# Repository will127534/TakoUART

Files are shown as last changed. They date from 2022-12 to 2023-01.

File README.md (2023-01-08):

# TakoUART - 8ch USB to UART board



This 5cm x 5cm 4-layer board is based on [CH348Q](http://www.wch-ic.com/products/CH348.html?) USB to 8 UART IC, I've also added level shifter (NTS0302JKZ) along with a overcurrent protector(NCP380) for user selectable 3.3V output on each UART port.

The board is designed with Kicad 6.0:



#inaART

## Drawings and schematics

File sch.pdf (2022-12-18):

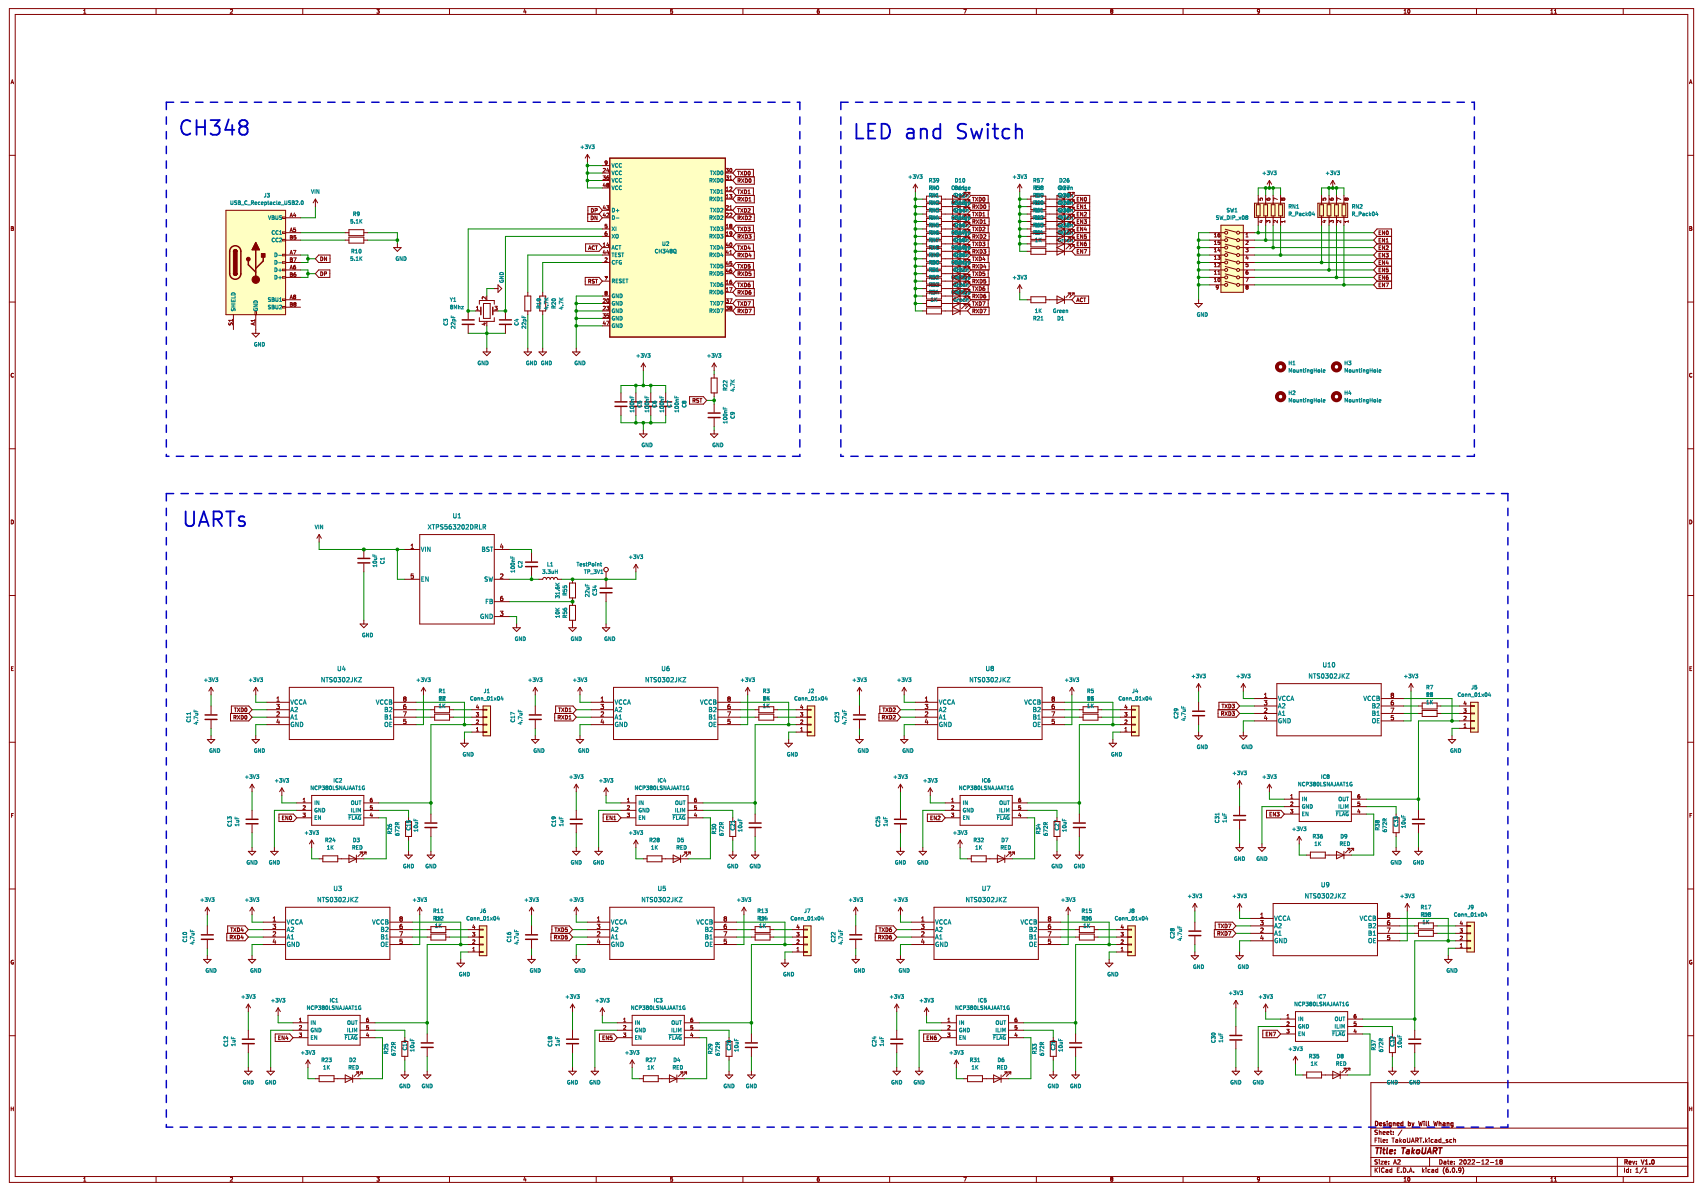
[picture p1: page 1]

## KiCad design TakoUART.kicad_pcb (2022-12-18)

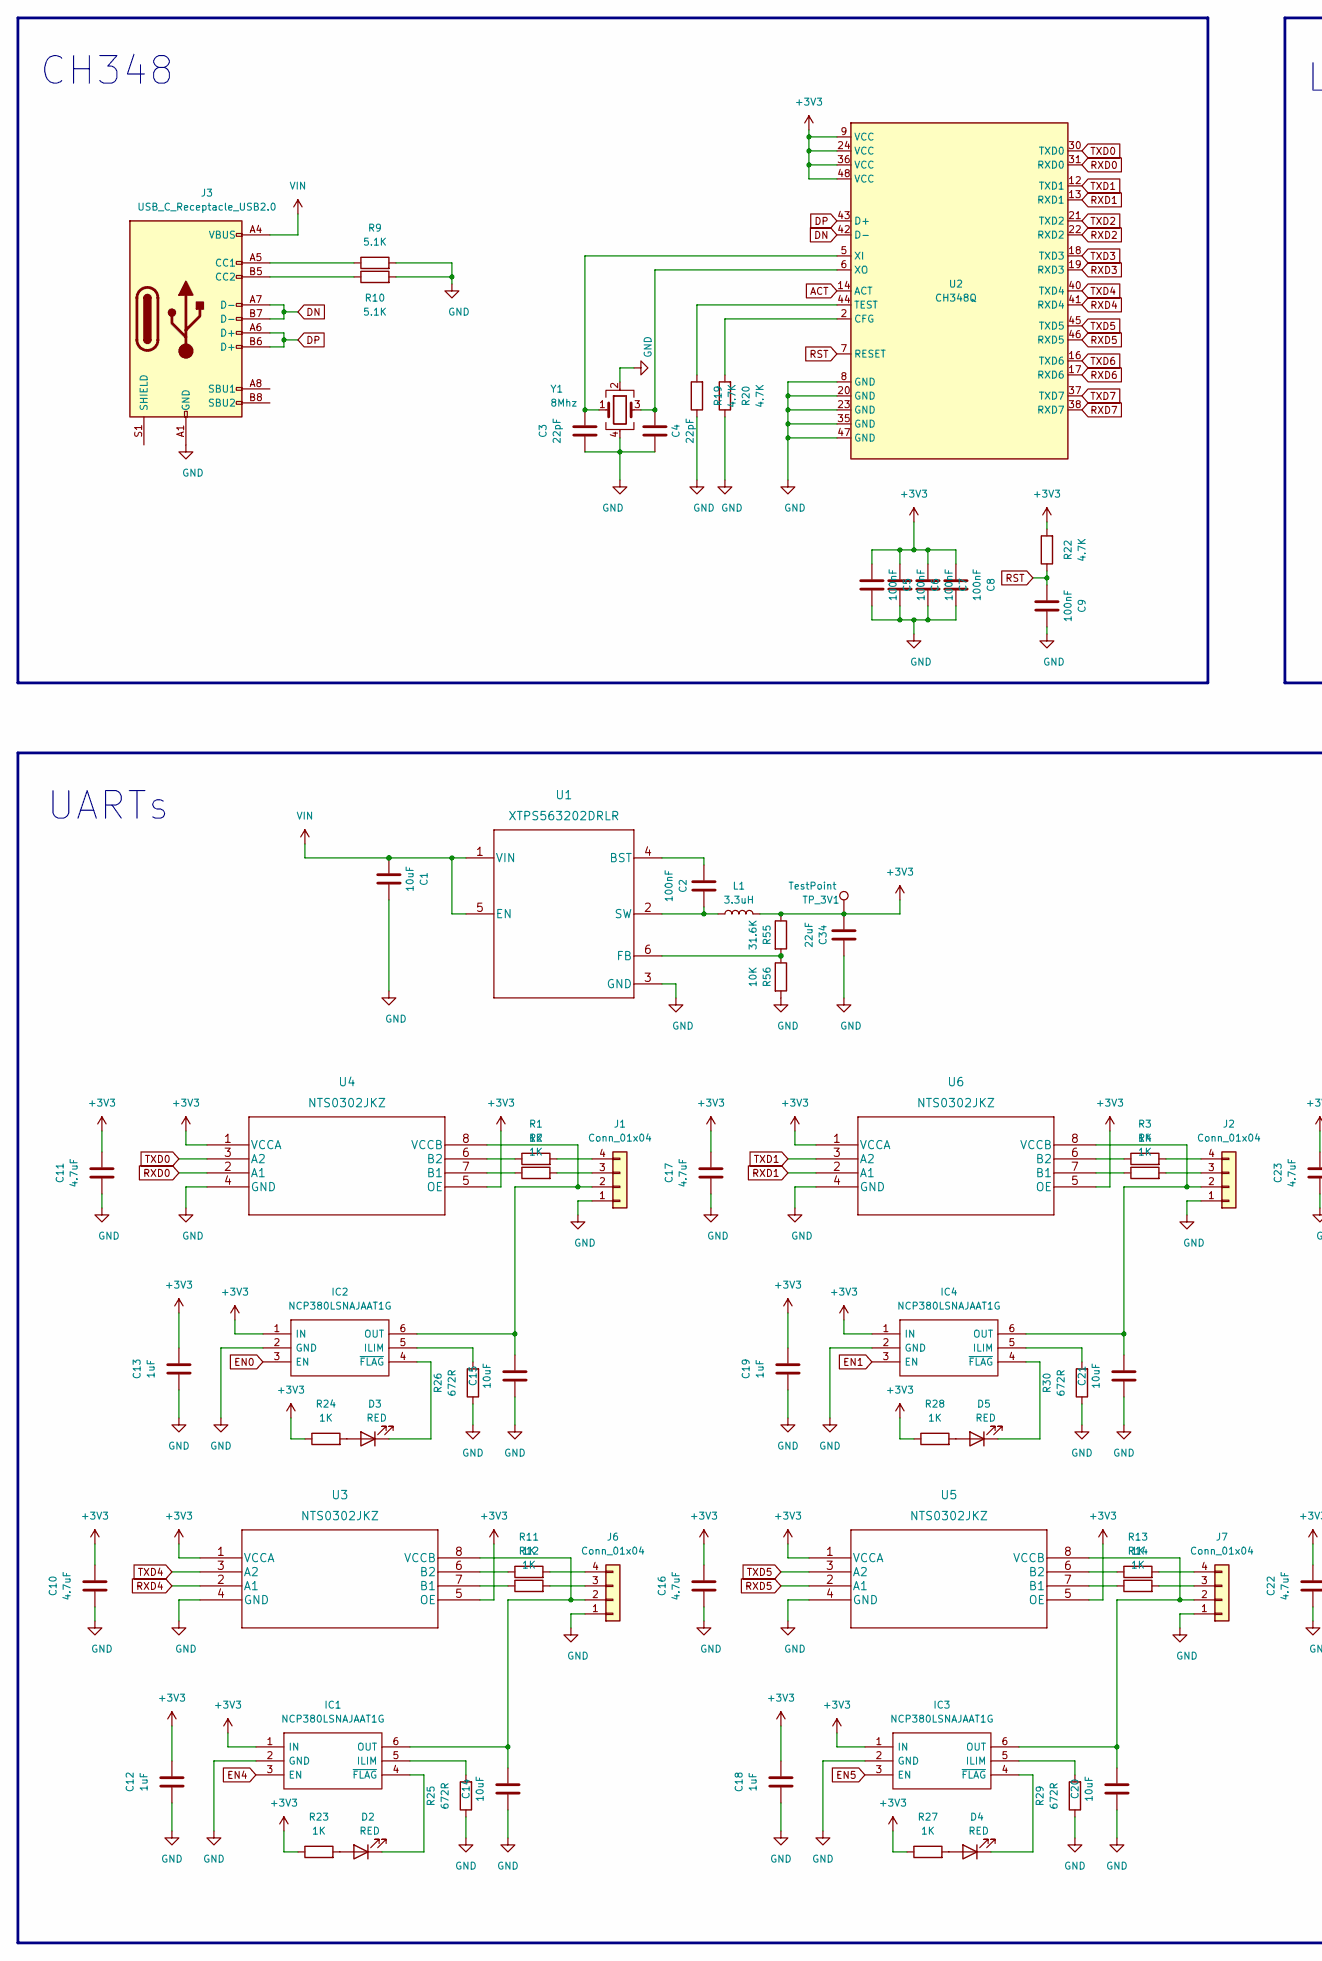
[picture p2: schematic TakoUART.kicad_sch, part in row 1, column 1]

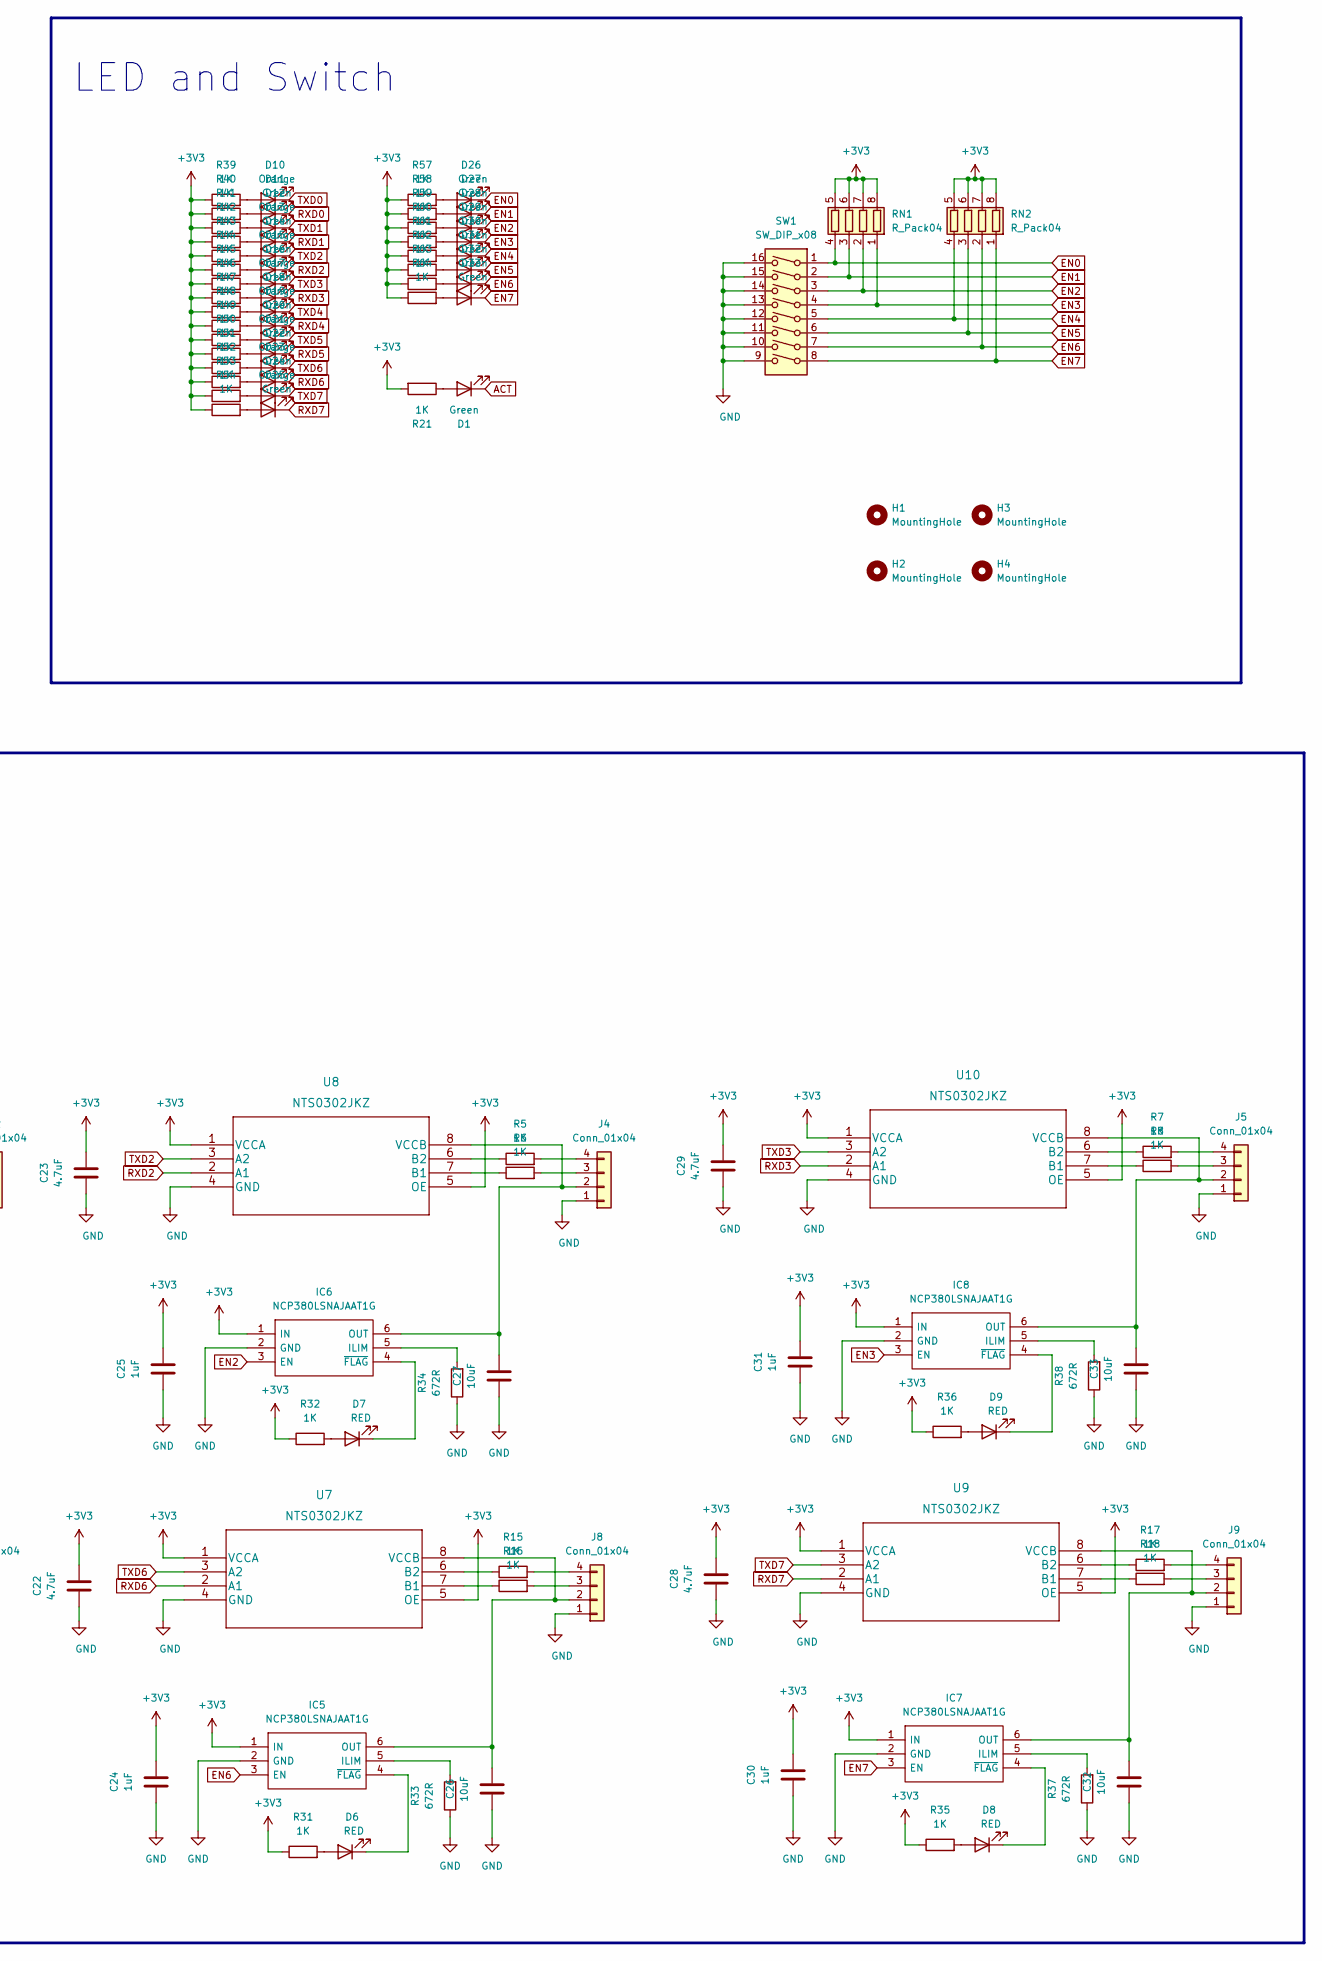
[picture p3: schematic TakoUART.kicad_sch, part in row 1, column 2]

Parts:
C1: 10uF; C_0805_2012Metric
C2, C5, C6, C7, C8, C9: 100nF; C_0402_1005Metric
C3, C4: 22pF; C_0402_1005Metric
C10, C11, C16, C17, C22, C23, C28, C29: 4.7uF; C_0402_1005Metric
C12, C13, C18, C19, C24, C25, C30, C31: 1uF; C_0402_1005Metric
C14, C15, C20, C21, C26, C27, C32, C33: 10uF; C_0402_1005Metric
C34: 22uF; C_0805_2012Metric
D1, D11, D13, D15, D17, D19, D21, D23, D25, D26, D27, D28, D29, D30, D31, D32, D33: Green; LED_0402_1005Metric
D2, D3, D4, D5, D6, D7, D8, D9: RED; LED_0402_1005Metric
D10, D12, D14, D16, D18, D20, D22, D24: Orange; LED_0402_1005Metric
H1, H2, H3, H4: MountingHole; MountingHole_3.2mm_M3
IC1, IC2, IC3, IC4, IC5, IC6, IC7, IC8: NCP380LSNAJAAT1G; SOT95P275X110-6N; Mouser Part Number 863-NCP380LSNAJAAT1G
J1, J2, J4, J5, J6, J7, J8, J9: Conn_01x04; JST_SH_BM04B-SRSS-TB_1x04-1MP_P1.00mm_Vertical
J3: USB_C_Receptacle_USB2.0; USB_C_Receptacle_XKB_U262-16XN-4BVC11
L1: 3.3uH; L_Vishay_IHLP-1212
R1, R2, R3, R4, R5, R6, R7, R8, R11, R12, R13, R14, R15, R16, R17, R18, R21, R23, R24, R27, R28, R31, R32, R35, R36, R39, R40, R41, R42, R43, R44, R45, R46, R47, R48, R49, R50, R51, R52, R53, R54, R57, R58, R59, R60, R61, R62, R63, R64: 1K; R_0402_1005Metric
R9, R10: 5.1K; R_0402_1005Metric
R19, R20, R22: 4.7K; R_0402_1005Metric
R25, R26, R29, R30, R33, R34, R37, R38: 672R; R_0402_1005Metric
R55: 31.6K; R_0402_1005Metric
R56: 10K; R_0402_1005Metric
RN1, RN2: R_Pack04; R_Array_Concave_4x0603
SW1: SW_DIP_x08; SW_DIP_SPSTx08_Slide_6.7x21.88mm_W8.61mm_P2.54mm_LowProfile
TP_3V1: TestPoint; TestPoint_Pad_D1.0mm
U1: XTPS563202DRLR
U2: CH348Q; LQFP-48_7x7mm_P0.5mm
U3, U4, U5, U6, U7, U8, U9, U10: NTS0302JKZ
Y1: 8Mhz; Crystal_SMD_3225-4Pin_3.2x2.5mm

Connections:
+3V3: C5.1, C6.1, C7.1, C8.1, C10.2, C11.2, C12.2, C13.2, C16.2, C17.2, C18.2, C19.2, C22.2, C23.2, C24.2, C25.2, C28.2, C29.2, C30.2, C31.2, C34.1, IC1.1 (IN), IC2.1 (IN), IC3.1 (IN), IC4.1 (IN), IC5.1 (IN), IC6.1 (IN), IC7.1 (IN), IC8.1 (IN), L1.2, R21.2, R22.2, R23.1, R24.1, R27.1, R28.1, R31.1, R32.1, R35.1, R36.1, R39.1, R40.1, R41.1, R42.1, R43.1, R44.1, R45.1, R46.1, R47.1, R48.1, R49.1, R50.1, R51.1, R52.1, R53.1, R54.1, R55.1, R57.1, R58.1, R59.1, R60.1, R61.1, R62.1, R63.1, R64.1, RN1.5 (R4.2), RN1.6 (R3.2), RN1.7 (R2.2), RN1.8 (R1.2), RN2.5 (R4.2), RN2.6 (R3.2), RN2.7 (R2.2), RN2.8 (R1.2), TP_3V1.1, U2.9 (VCC), U2.24 (VCC), U2.36 (VCC), U2.48 (VCC), U3.1 (VCCA), U3.5 (OE), U4.1 (VCCA), U4.5 (OE), U5.1 (VCCA), U5.5 (OE), U6.1 (VCCA), U6.5 (OE), U7.1 (VCCA), U7.5 (OE), U8.1 (VCCA), U8.5 (OE), U9.1 (VCCA), U9.5 (OE), U10.1 (VCCA), U10.5 (OE)
ACT: D1.1 (K), U2.14 (ACT)
DN: J3.A7 (D-), J3.B7 (D-), U2.42 (D-)
DP: J3.A6 (D+), J3.B6 (D+), U2.43 (D+)
EN0: D26.1 (K), IC2.3 (EN), RN1.4 (R4.1), SW1.1
EN1: D27.1 (K), IC4.3 (EN), RN1.3 (R3.1), SW1.2
EN2: D28.1 (K), IC6.3 (EN), RN1.2 (R2.1), SW1.3
EN3: D29.1 (K), IC8.3 (EN), RN1.1 (R1.1), SW1.4
EN4: D30.1 (K), IC1.3 (EN), RN2.4 (R4.1), SW1.5
EN5: D31.1 (K), IC3.3 (EN), RN2.3 (R3.1), SW1.6
EN6: D32.1 (K), IC5.3 (EN), RN2.2 (R2.1), SW1.7
EN7: D33.1 (K), IC7.3 (EN), RN2.1 (R1.1), SW1.8
GND: C1.2, C3.1, C4.1, C5.2, C6.2, C7.2, C8.2, C9.2, C10.1, C11.1, C12.1, C13.1, C14.1, C15.1, C16.1, C17.1, C18.1, C19.1, C20.1, C21.1, C22.1, C23.1, C24.1, C25.1, C26.1, C27.1, C28.1, C29.1, C30.1, C31.1, C32.1, C33.1, C34.2, IC1.2 (GND), IC2.2 (GND), IC3.2 (GND), IC4.2 (GND), IC5.2 (GND), IC6.2 (GND), IC7.2 (GND), IC8.2 (GND), J1.1, J2.1, J3.A1 (GND), J3.A12 (GND), J3.B1 (GND), J3.B12 (GND), J4.1, J5.1, J6.1, J7.1, J8.1, J9.1, R9.2, R10.2, R19.1, R20.1, R25.1, R26.1, R29.1, R30.1, R33.1, R34.1, R37.1, R38.1, R56.2, SW1.9, SW1.10, SW1.11, SW1.12, SW1.13, SW1.14, SW1.15, SW1.16, U1.3 (GND), U2.8 (GND), U2.20 (GND), U2.23 (GND), U2.35 (GND), U2.47 (GND), U3.4 (GND), U4.4 (GND), U5.4 (GND), U6.4 (GND), U7.4 (GND), U8.4 (GND), U9.4 (GND), U10.4 (GND), Y1.2, Y1.4
unnamed: C2.1, U1.4 (BST)
unnamed: C2.2, L1.1, U1.2 (SW)
unnamed: C3.2, U2.5 (XI), Y1.1
unnamed: C4.2, U2.6 (XO), Y1.3
unnamed: C14.2, IC1.6 (OUT), J6.2, U3.8 (VCCB)
unnamed: C15.2, IC2.6 (OUT), J1.2, U4.8 (VCCB)
unnamed: C20.2, IC3.6 (OUT), J7.2, U5.8 (VCCB)
unnamed: C21.2, IC4.6 (OUT), J2.2, U6.8 (VCCB)
unnamed: C26.2, IC5.6 (OUT), J8.2, U7.8 (VCCB)
unnamed: C27.2, IC6.6 (OUT), J4.2, U8.8 (VCCB)
unnamed: C32.2, IC7.6 (OUT), J9.2, U9.8 (VCCB)
unnamed: C33.2, IC8.6 (OUT), J5.2, U10.8 (VCCB)
unnamed: D1.2 (A), R21.1
unnamed: D2.1 (K), IC1.4 (~FLAG)
unnamed: D2.2 (A), R23.2
unnamed: D3.1 (K), IC2.4 (~FLAG)
unnamed: D3.2 (A), R24.2
unnamed: D4.1 (K), IC3.4 (~FLAG)
unnamed: D4.2 (A), R27.2
unnamed: D5.1 (K), IC4.4 (~FLAG)
unnamed: D5.2 (A), R28.2
unnamed: D6.1 (K), IC5.4 (~FLAG)
unnamed: D6.2 (A), R31.2
unnamed: D7.1 (K), IC6.4 (~FLAG)
unnamed: D7.2 (A), R32.2
unnamed: D8.1 (K), IC7.4 (~FLAG)
unnamed: D8.2 (A), R35.2
unnamed: D9.1 (K), IC8.4 (~FLAG)
unnamed: D9.2 (A), R36.2
unnamed: D10.2 (A), R39.2
unnamed: D11.2 (A), R40.2
unnamed: D12.2 (A), R41.2
unnamed: D13.2 (A), R42.2
unnamed: D14.2 (A), R43.2
unnamed: D15.2 (A), R44.2
unnamed: D16.2 (A), R45.2
unnamed: D17.2 (A), R46.2
unnamed: D18.2 (A), R47.2
unnamed: D19.2 (A), R48.2
unnamed: D20.2 (A), R49.2
unnamed: D21.2 (A), R50.2
unnamed: D22.2 (A), R51.2
unnamed: D23.2 (A), R52.2
unnamed: D24.2 (A), R53.2
unnamed: D25.2 (A), R54.2
unnamed: D26.2 (A), R57.2
unnamed: D27.2 (A), R58.2
unnamed: D28.2 (A), R59.2
unnamed: D29.2 (A), R60.2
unnamed: D30.2 (A), R61.2
unnamed: D31.2 (A), R62.2
unnamed: D32.2 (A), R63.2
unnamed: D33.2 (A), R64.2
unnamed: IC1.5 (ILIM), R25.2
unnamed: IC2.5 (ILIM), R26.2
unnamed: IC3.5 (ILIM), R29.2
unnamed: IC4.5 (ILIM), R30.2
unnamed: IC5.5 (ILIM), R33.2
unnamed: IC6.5 (ILIM), R34.2
unnamed: IC7.5 (ILIM), R37.2
unnamed: IC8.5 (ILIM), R38.2
unnamed: J1.3, R2.2
unnamed: J1.4, R1.2
unnamed: J2.3, R4.2
unnamed: J2.4, R3.2
unnamed: J3.A5 (CC1), R9.1
unnamed: J3.B5 (CC2), R10.1
unnamed: J4.3, R6.2
unnamed: J4.4, R5.2
unnamed: J5.3, R8.2
unnamed: J5.4, R7.2
unnamed: J6.3, R12.2
unnamed: J6.4, R11.2
unnamed: J7.3, R14.2
unnamed: J7.4, R13.2
unnamed: J8.3, R16.2
unnamed: J8.4, R15.2
unnamed: J9.3, R18.2
unnamed: J9.4, R17.2
unnamed: R1.1, U4.6 (B2)
unnamed: R2.1, U4.7 (B1)
unnamed: R3.1, U6.6 (B2)
unnamed: R4.1, U6.7 (B1)
unnamed: R5.1, U8.6 (B2)
unnamed: R6.1, U8.7 (B1)
unnamed: R7.1, U10.6 (B2)
unnamed: R8.1, U10.7 (B1)
unnamed: R11.1, U3.6 (B2)
unnamed: R12.1, U3.7 (B1)
unnamed: R13.1, U5.6 (B2)
unnamed: R14.1, U5.7 (B1)
unnamed: R15.1, U7.6 (B2)
unnamed: R16.1, U7.7 (B1)
unnamed: R17.1, U9.6 (B2)
unnamed: R18.1, U9.7 (B1)
unnamed: R19.2, U2.44 (TEST)
unnamed: R20.2, U2.2 (CFG)
unnamed: R55.2, R56.1, U1.6 (FB)
RST: C9.1, R22.1, U2.7 (RESET)
RXD0: D11.1 (K), U2.31 (RXD0), U4.2 (A1)
RXD1: D13.1 (K), U2.13 (RXD1), U6.2 (A1)
RXD2: D15.1 (K), U2.22 (RXD2), U8.2 (A1)
RXD3: D17.1 (K), U2.19 (RXD3), U10.2 (A1)
RXD4: D19.1 (K), U2.41 (RXD4), U3.2 (A1)
RXD5: D21.1 (K), U2.46 (RXD5), U5.2 (A1)
RXD6: D23.1 (K), U2.17 (RXD6), U7.2 (A1)
RXD7: D25.1 (K), U2.38 (RXD7), U9.2 (A1)
TXD0: D10.1 (K), U2.30 (TXD0), U4.3 (A2)
TXD1: D12.1 (K), U2.12 (TXD1), U6.3 (A2)
TXD2: D14.1 (K), U2.21 (TXD2), U8.3 (A2)
TXD3: D16.1 (K), U2.18 (TXD3), U10.3 (A2)
TXD4: D18.1 (K), U2.40 (TXD4), U3.3 (A2)
TXD5: D20.1 (K), U2.45 (TXD5), U5.3 (A2)
TXD6: D22.1 (K), U2.16 (TXD6), U7.3 (A2)
TXD7: D24.1 (K), U2.37 (TXD7), U9.3 (A2)
VIN: C1.1, J3.A4 (VBUS), J3.A9 (VBUS), J3.B4 (VBUS), J3.B9 (VBUS), U1.1 (VIN), U1.5 (EN)

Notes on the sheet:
UARTs
CH348
LED and Switch

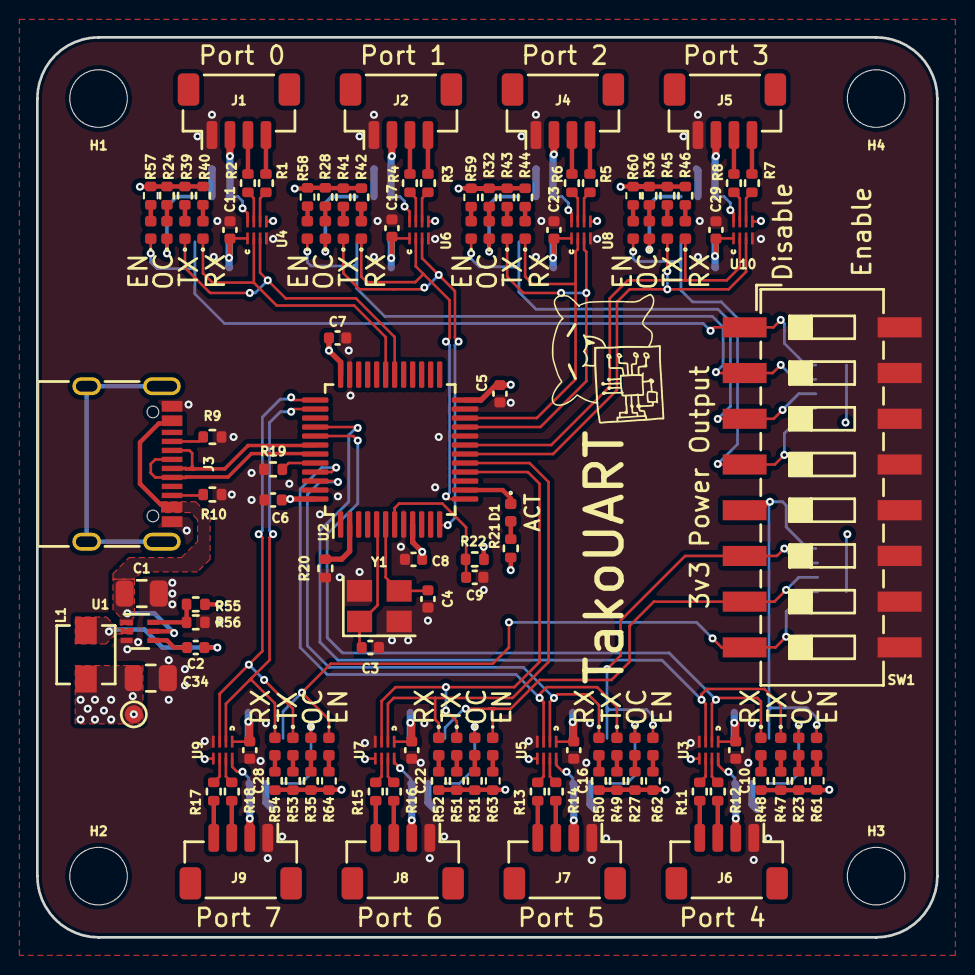
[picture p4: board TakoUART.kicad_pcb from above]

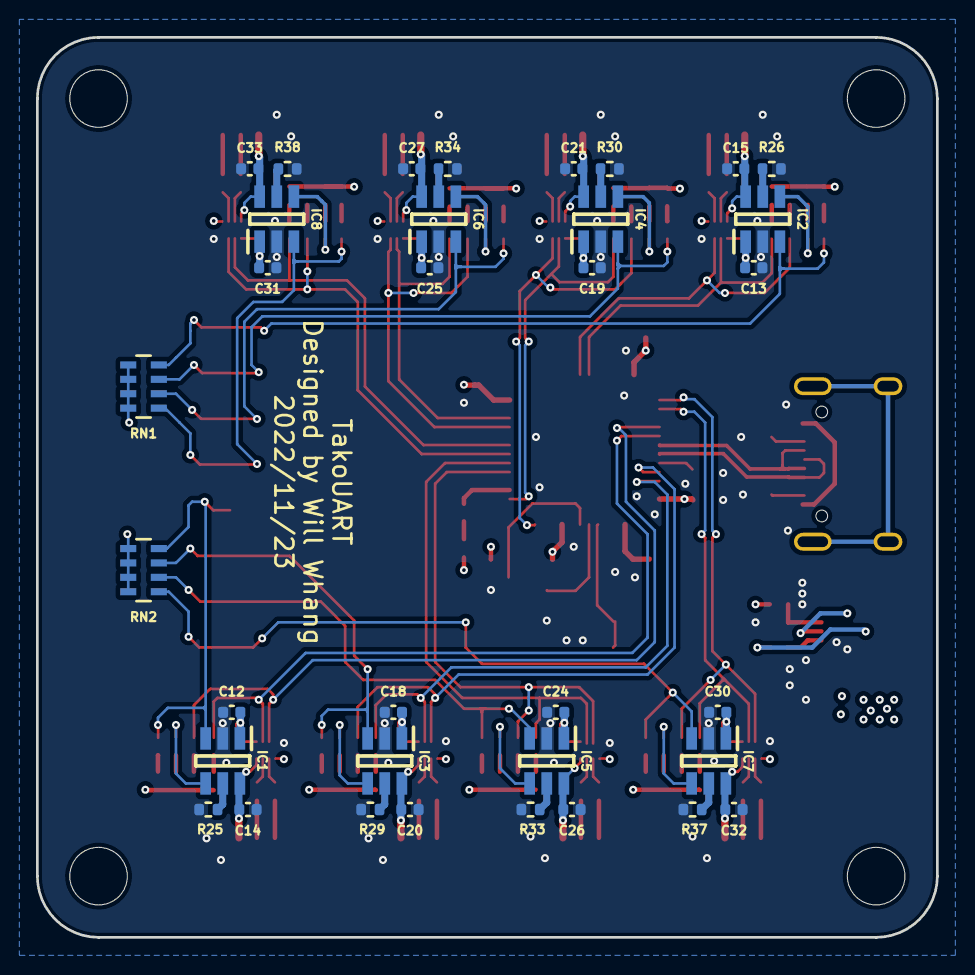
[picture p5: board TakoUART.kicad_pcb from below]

Board: 4 copper layers, 50.0 x 50.0 mm, 168 parts (34 on the bottom side), 129 nets.

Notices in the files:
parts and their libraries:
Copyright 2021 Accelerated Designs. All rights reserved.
